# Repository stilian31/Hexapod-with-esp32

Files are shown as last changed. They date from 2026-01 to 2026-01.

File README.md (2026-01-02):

# Hexapod-with-esp32
this is a custom control board for a six-legged (hexapod) robot. It’s built around the ESP32-S3 WROOM and uses two PCA9685 drivers to precisely control all servos. The robot can be easily controlled via a joystick, making movement intuitive and fun. Designed for DIY robotics projects and expandable with sensors or LEDs.
The 3D model of the hexapod IS NOT mine.I've adapted the 3D model for my PCB :)
If you have any questions you can text me on instagram @funtronics_ or @stilianskordas and on my gmail - stilianskordas08@gmail.com :). I will answer any time.

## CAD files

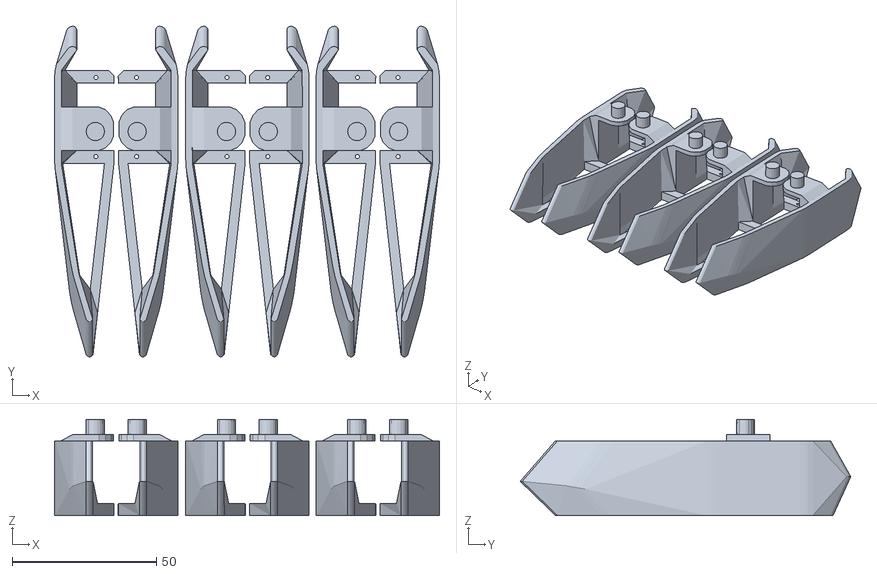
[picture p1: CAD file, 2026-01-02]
mwilmars/sword-leg-hexapod-robot/tibia.stl
133.4 x 114.5 x 33.3

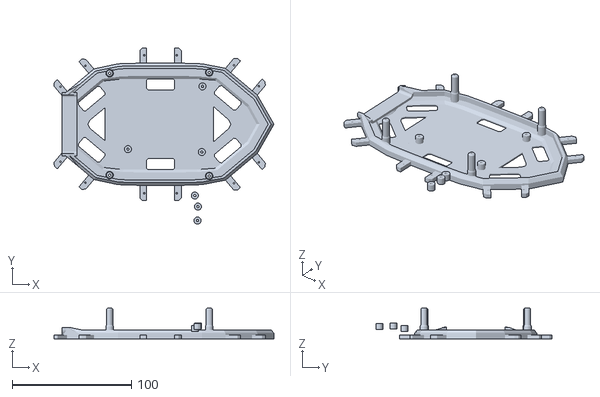
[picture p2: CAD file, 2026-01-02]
mwilmars/sword-leg-hexapod-robot/bottom.stl
184.4 x 147.8 x 25.7

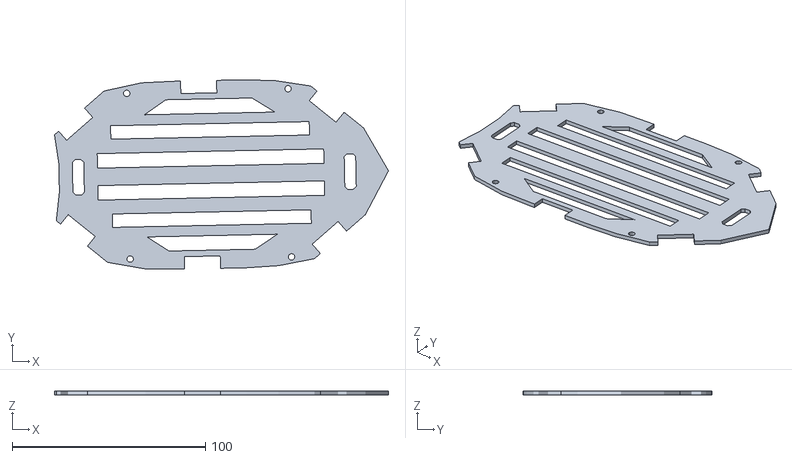
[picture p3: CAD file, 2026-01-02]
mwilmars/sword-leg-hexapod-robot/cover_top.stl
172.7 x 97.9 x 2.00

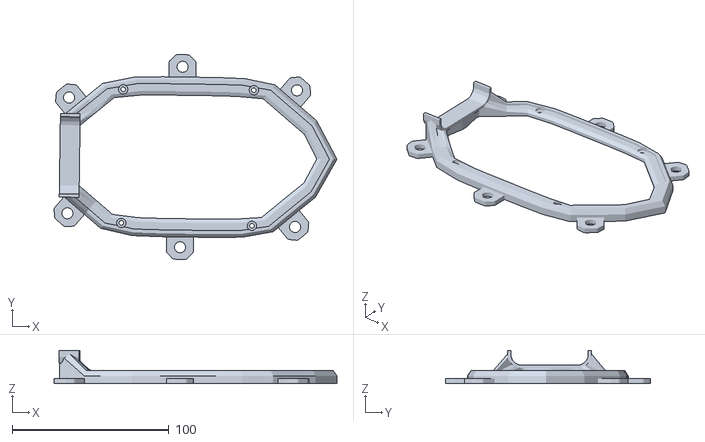
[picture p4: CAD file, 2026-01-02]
mwilmars/sword-leg-hexapod-robot/body_top.stl
180.8 x 130.8 x 21.3

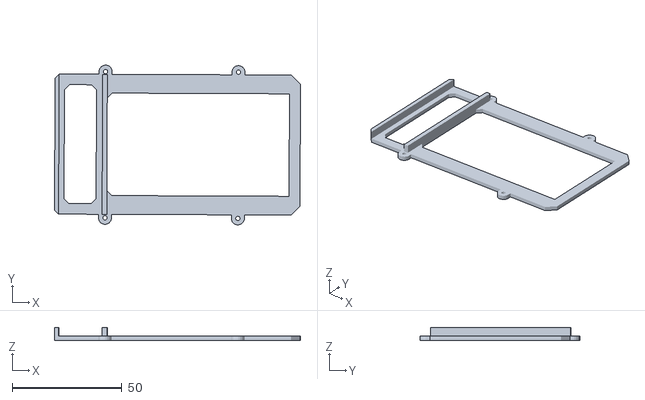
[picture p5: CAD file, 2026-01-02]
mwilmars/sword-leg-hexapod-robot/board_bracket.stl
112.2 x 72.9 x 5.89

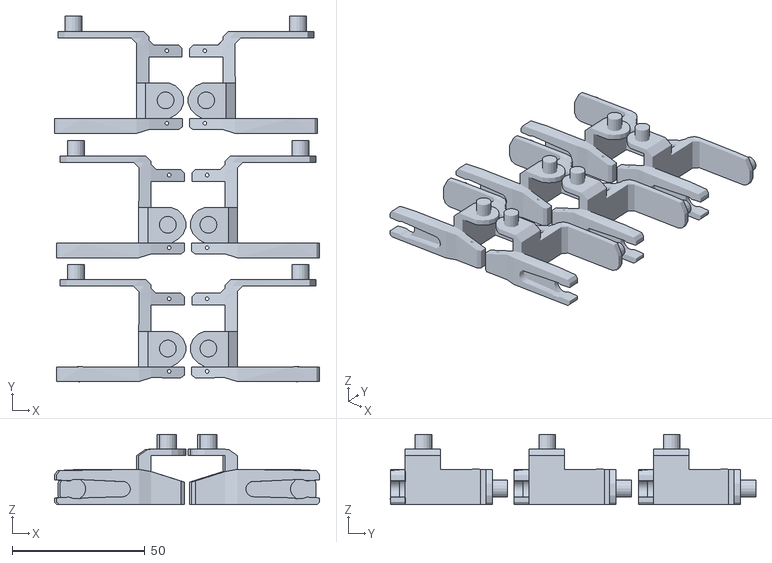
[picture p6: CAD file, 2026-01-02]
mwilmars/sword-leg-hexapod-robot/coxa.stl
99.9 x 137.9 x 26.6

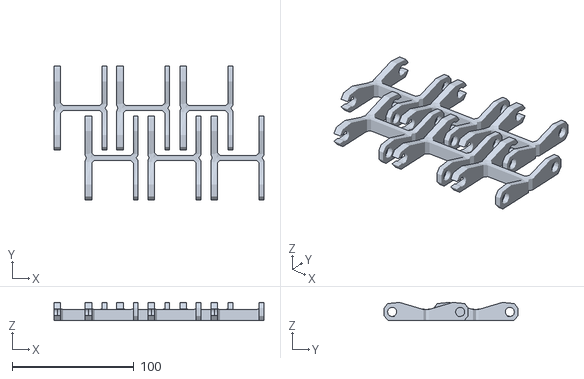
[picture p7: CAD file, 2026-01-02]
mwilmars/sword-leg-hexapod-robot/femur.stl
172.4 x 109.7 x 15.0

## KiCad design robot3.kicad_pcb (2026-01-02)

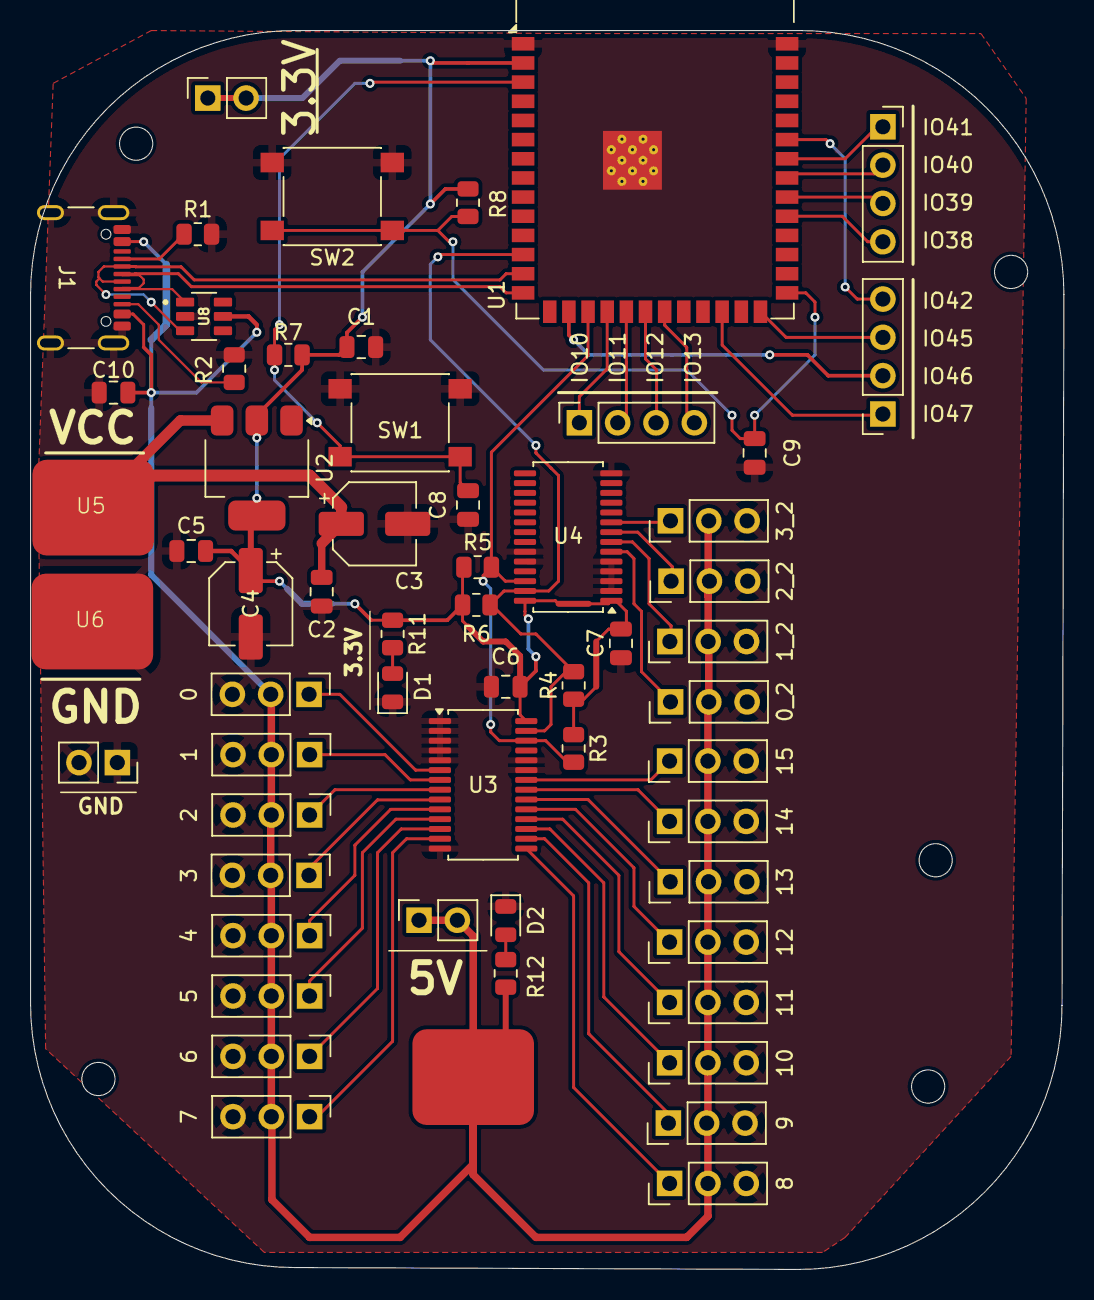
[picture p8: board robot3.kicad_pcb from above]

Board: 2 copper layers, 68.5 x 82.1 mm, 59 parts (0 on the bottom side), 46 nets.

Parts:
0, 0_2, 1, 2, 2_2, 3, 4, 5, 6, 7, 8, 9, 10, 11, 12, 13, 14, 15: Conn_01x03_Pin; PinHeader_1x03_P2.54mm_Vertical
C1, C2, C5, C6, C7, C8, C9, C10: 100nF; C_0805_2012Metric
C3, C4: 10uF; CP_Elec_5x5.4
D1, D2: LED; LED_0805_2012Metric
J1: USB_C_Receptacle_USB2.0_16P; USB_C_Receptacle_GCT_USB4105-xx-A_16P_TopMnt_Horizontal
J19, J21: Conn_01x03_Pin; PinHeader_1x03_P2.54mm_Vertical
J22, J23, J24: Conn_01x04_Pin; PinSocket_1x04_P2.54mm_Vertical
J26, J27, J28: Conn_01x02_Pin; PinSocket_1x02_P2.54mm_Vertical
R1, R2: 5.1k; R_0805_2012Metric
R3, R5, R11, R12: R; R_0805_2012Metric
R4, R6: 4.7k; R_0805_2012Metric
R7, R8: 10k; R_0805_2012Metric
SW1, SW2: SW_Push; SW_SPST_PTS645
U1: ESP32-S3-WROOM-1
U2: AMS1117-3.3; SOT-223-3_TabPin2
U3, U4: PCA9685PW; TSSOP-28_4.4x9.7mm_P0.65mm
U5, U6, U7: pad
U8: USBLC6-2SC6

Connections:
+3.3V: C1.2, C4.1, C5.2, C6.2, C7.2, J27.1, J27.2, R3.1, R4.1, R5.1, R6.1, R7.1, R8.1, R11.1, U1.2 (3V3), U2.2 (VO), U3.28 (VDD), U4.1 (A0), U4.28 (VDD)
+5V: 0.2, 0_2.2, 1.2, 2.2, 2_2.2, 3.2, 4.2, 5.2, 6.2, 7.2, 8.2, 9.2, 10.2, 11.2, 12.2, 13.2, 14.2, 15.2, C10.1, J1.A4 (VBUS), J1.A9 (VBUS), J1.B4 (VBUS), J1.B9 (VBUS), J19.2, J21.2, J28.1, J28.2, R12.1, U7.1, U8.5
D+: J1.A6 (D+), J1.B6 (D+), U1.14 (USB_D+), U8.1
D-: J1.A7 (D-), J1.B7 (D-), U1.13 (USB_D-), U8.3
GND: 0.3, 0_2.3, 1.3, 2.3, 2_2.3, 3.3, 4.3, 5.3, 6.3, 7.3, 8.3, 9.3, 10.3, 11.3, 12.3, 13.3, 14.3, 15.3, C1.1, C2.1, C3.2, C4.2, C5.1, C6.1, C7.1, C8.2, C9.2, C10.2, D1.1 (K), D2.1 (K), J1.A1 (GND), J1.A12 (GND), J1.B1 (GND), J1.B12 (GND), J1.S1 (SHIELD), J19.3, J21.3, J26.1, J26.2, R1.2, R2.2, SW1.2, SW2.2, U1.1 (GND), U1.40 (GND), U1.41 (GND), U3.1 (A0), U3.2 (A1), U3.3 (A2), U3.4 (A3), U3.5 (A4), U3.14 (VSS), U3.23 (~OE), U3.24 (A5), U4.2 (A1), U4.3 (A2), U4.4 (A3), U4.5 (A4), U4.14 (VSS), U4.23 (~OE), U4.24 (A5), U6.1, U8.2
IO0: C9.1, R8.2, SW2.1, U1.27 (IO0)
IO8 SDA: R4.2, R6.2, U1.12 (IO8), U3.27 (SDA), U4.27 (SDA)
IO9 SCL: R3.2, R5.2, U1.17 (IO9), U3.26 (SCL), U4.26 (SCL)
LED0: 0.1, U3.6 (LED0)
LED0_2: 0_2.1, U4.6 (LED0)
LED1: 1.1, U3.7 (LED1)
LED1_2: J19.1, U4.7 (LED1)
LED2: 2.1, U3.8 (LED2)
LED2_2: 2_2.1, U4.8 (LED2)
LED3: 3.1, U3.9 (LED3)
LED3_2: J21.1, U4.9 (LED3)
LED4: 4.1, U3.10 (LED4)
LED5: 5.1, U3.11 (LED5)
LED6: 6.1, U3.12 (LED6)
LED7: 7.1, U3.13 (LED7)
LED8: 8.1, U3.15 (LED8)
LED9: 9.1, U3.16 (LED9)
LED10: 10.1, U3.17 (LED10)
LED11: 11.1, U3.18 (LED11)
LED12: 12.1, U3.19 (LED12)
LED13: 13.1, U3.20 (LED13)
LED14: 14.1, U3.21 (LED14)
LED15: 15.1, U3.22 (LED15)
unnamed: D1.2 (A), R11.2
unnamed: D2.2 (A), R12.2
unnamed: J1.A5 (CC1), R1.1
unnamed: J1.B5 (CC2), R2.1
unnamed: J22.1, U1.34 (IO41)
unnamed: J22.2, U1.33 (IO40)
unnamed: J22.3, U1.32 (IO39)
unnamed: J22.4, U1.31 (IO38)
unnamed: J23.1, U1.24 (IO47)
unnamed: J23.2, U1.16 (IO46)
unnamed: J23.3, U1.26 (IO45)
unnamed: J23.4, U1.35 (IO42)
unnamed: J24.1, U1.18 (IO10)
unnamed: J24.2, U1.19 (IO11)
unnamed: J24.3, U1.20 (IO12)
unnamed: J24.4, U1.21 (IO13)
unnamed: C8.1, R7.2, SW1.1, U1.3 (EN)
VCC: C2.2, C3.1, U2.3 (VI), U5.1
